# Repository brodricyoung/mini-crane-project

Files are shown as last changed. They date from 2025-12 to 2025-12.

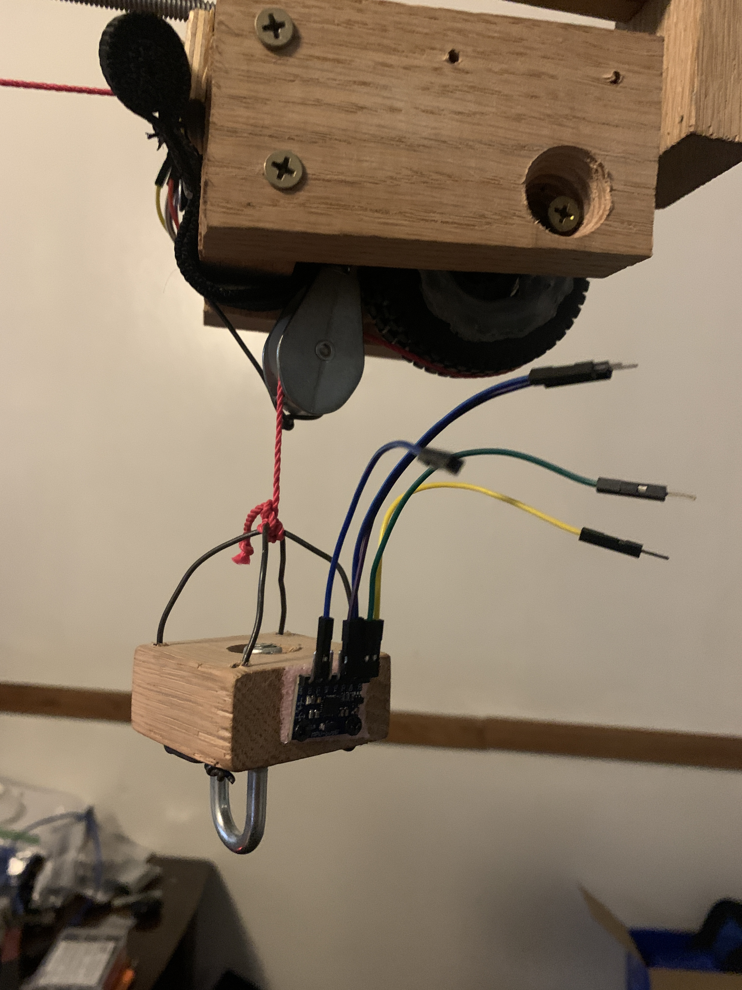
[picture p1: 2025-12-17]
Documentation/images/components-in-system/MPU-and-hook.JPG

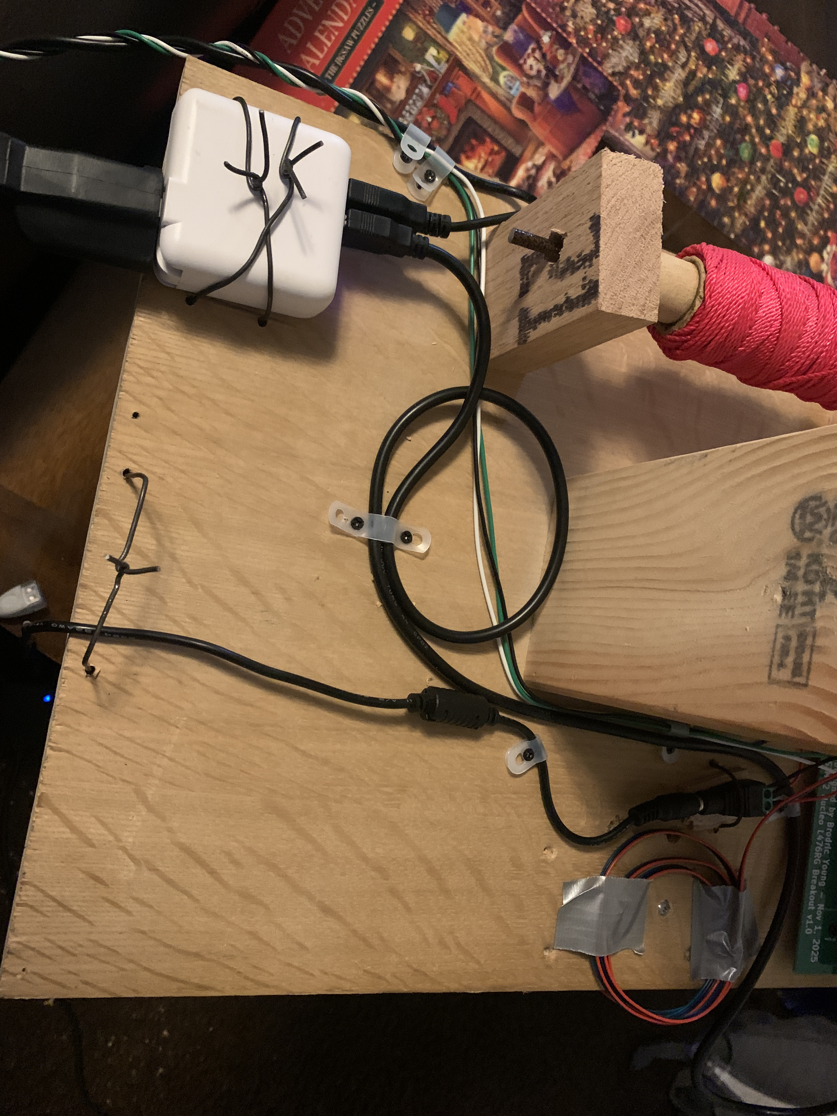
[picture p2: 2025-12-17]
Documentation/images/components-in-system/power-supply.JPG

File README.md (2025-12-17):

# Mini Crane Project

This repository contains the documentation and resources for my Mini Crane project, completed as part of my Individual Technical Project for professional career preparation. The project demonstrates a crane system controlled by an STM32 Nucleo microcontroller, with sensors and manual controls for crane motion and hook manipulation.

---

## 📄 Project Report

The full project report PDF is available here:

*(download for best experience navigating and for links)*

[Mini Crane Project Report](https://github.com/brodricyoung/mini-crane-project/blob/main/Documentation/Mini_Crane_Project_Report.pdf)

---

## 🖼 Images

Images of the crane assembly, components, and system setup, and schematics are included in the `images` folder:

[Images](./Documentation/images/)

---

## 🎥 Project Demo Video

Watch the project in action so far on YouTube:

[Mini Crane Demo #1](https://youtu.be/VVNfatb6yKk)

---

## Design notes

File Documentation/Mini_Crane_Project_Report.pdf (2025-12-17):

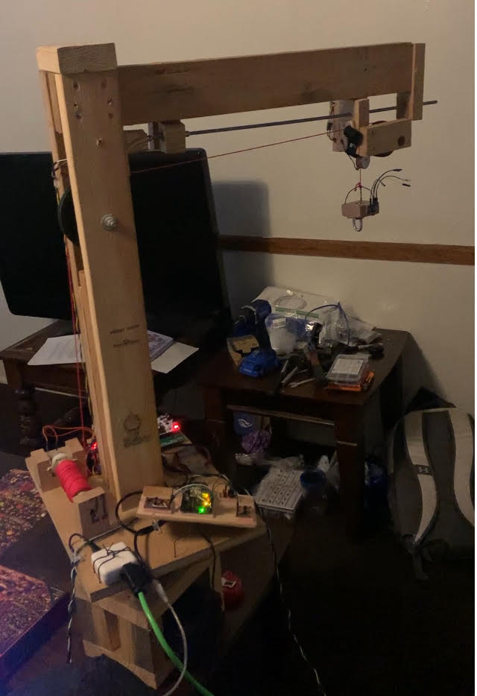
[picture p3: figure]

## Mini Crane Project

### Brodric Young

December 16, 2025

## Contents

1 Project Overview | 3
2 Specifications | 4
3 Project Procedures | 6
4 Code | 10
5 Conclusion | 11

1

## List of Tables

## List of Figures

1 | Pinout diagram for the STM32 microcontroller | | 6
2 | Pinout diagram for the Arduino microcontroller | | 7
3 | Pinout diagram for the L298N module driving the DC motors | | 7
4 | Pinout diagram for the L298N module driving the stepper motor | | 7
5 | Block diagram of the full system | | 8

2

## 1 Project Overview

The goal of this project was to design and build a miniature crane system controlled by an STM32 microcontroller, with the long-term goal of implementing automatic swing compensation for a suspended load. The crane was intended to demonstrate the integration of embedded systems, motor control, sensing, mechanical design, and communication between microcontrollers.

### 1.1 Github link

The full projects files can be found on Github here:

- Mini Crane Project (https://github.com/brodricyoung/mini-crane-project/tree/main)

### 1.2 System Overview

The mini crane consists of a wooden mechanical structure, multiple motors, sensors, and two microcontrollers communicating via UART. The system allows manual control through a handheld controller while collecting sensor data for future automation.

### 1.3 Objectives

- Designing a custom PCB to interface with an STM32 Nucleo board
- Controlling multiple motors (stepper and DC) for crane motion
- Measuring hook position using a rotary encoder
- Detecting load swing using an inertial measurement unit (IMU)
- Using sensors and motors for autonomous swing compensation

3

## 2 Specifications

The following parts list outlines the primary electrical, mechanical, and structural components used in the construction of the mini crane system. Components were selected to support motor control, sensor integration, and communication between microcontrollers while remaining modular and serviceable. Emphasis was placed on using commonly available hardware and development boards to allow for rapid prototyping, debugging, and future system expansion.

### 2.1 Parts List

- STM32 Nucleo development board (main crane controller) (https://www.st.com/en/evaluation-tools/nucleo-l476rg.html)
- Custom-designed STM32 breakout PCB (KiCad) (https://github.com/brodricyoung/mini-crane-project/tree/main/KiCad_files_for_PCB)
- Arduino microcontroller (handheld controller) (https://docs.arduino.cc/hardware/uno-rev3/)
- Two L298N motor driver modules (https://www.amazon.com/dp/B0CLYBPGP9?ref=ppx_yo2ov_dt_b_fed_asin_title)
- NEMA 17 stepper motor (crane rotation) (https://www.amazon.com/dp/B07SC8HJMC?ref=ppx_yo2ov_dt_b_fed_asin_title&th=1)
- Two 10 RPM DC gear motors (winch and trolley drive) (https://www.amazon.com/dp/B07S2KWRWQ?ref=ppx_yo2ov_dt_b_fed_asin_title&th=1)
- 1/4 in threaded rod and matching flange nut (trolley linear motion) (https://github.com/brodricyoung/mini-crane-project/blob/main/Documentation/images/components-in-system/trolley-and-threaded-rod.JPG)
- Rotary encoder module (rope length measurement) (https://www.amazon.com/dp/B0DFYLNWPJ?ref=ppx_yo2ov_dt_b_fed_asin_title&th=1)
- MPU-6050 IMU module (swing detection sensor) (https://www.amazon.com/dp/B01DK83ZYQ?ref=ppx_yo2ov_dt_b_fed_asin_title&th=1)
- Handheld controller protoboards with push buttons (motor control), buzzer, and LED (swing compensation indicators) (https://github.com/brodricyoung/mini-crane-project/blob/main/Documentation/images/components-in-system/handheld-arduino-controller.JPG)
- UART communication wiring between Arduino and STM32
- 5mm flange coupling connectors (motors) (https://www.amazon.com/dp/B08334MFVT?ref=ppx_yo2ov_dt_b_fed_asin_title&th=1)
- 6.35mm flange coupling connectors (threaded rod and rotary encoder) (https://www.amazon.com/dp/B08334YZ9V?ref=ppx_yo2ov_dt_b_fed_asin_title&th=1)
- Bearing for crane rotation (https://www.amazon.com/dp/B0BBL46B8Y?ref=ppx_yo2ov_dt_b_fed_asin_title&th=1)
- Pulleys and rope for winch mechanism
- Wooden structural components (frame and boom)
- 12V power supply (motor driver modules) (https://www.amazon.com/dp/B0C22Z8DPL?ref=ppx_yo2ov_dt_b_fed_asin_title)
- 5V USB power supply for microcontrollers (https://github.com/brodricyoung/mini-crane-project/blob/main/Documentation/images/components-in-system/power-supply.JPG)

4

### 2.2 System Images and Demonstration Media

This subsection provides external references to visual documentation of the completed mini crane system. High-resolution images showing each major component integrated into the final assembly, as well as a demonstration video of the system in operation, are hosted online in the project Github repository to avoid overloading the report with large media files. These resources offer additional context for the mechanical layout, wiring, and overall system behavior.

- GitHub repository folder containing system images (https://github.com/brodricyoung/mini-crane-project/tree/main/Documentation/images/components-in-system)
- Project demonstration video (https://www.youtube.com/watch?v=VVNfatb6yKk)

5

## 3 Project Procedures

This section documents the design and implementation of the mini crane system using a combination of pinout diagrams, block diagrams, and written descriptions. Electrical schematics were created in the form of detailed pinout diagrams using Google Sheets to clearly illustrate the connections between the STM32 Nucleo board, motor drivers, sensors, and peripheral devices. This approach allowed for rapid iteration and easy modification as the project evolved.
In addition, a system-level block diagram is provided to describe the overall architecture of the crane, including control flow, power distribution, and communication between subsystems. The written block diagram description complements the visual diagram by explaining the functional role of each subsystem and how they interact during operation. Together, these materials provide a clear representation of both the electrical and logical structure of the project.

Notes:

- The ”slew” in the diagrams refers to the NEMA 17 stepper motor
- The ”winch” and ”trolley” in the diagrams refer to the two 10 RPM DC gear motors
- ”L298N [A]” in the diagrams refers to the L298N motor driver module driving the two DC motors
- ”L298N [B]” in the diagrams refers to the L298N motor driver module driving the NEMA 17 stepper motor

### 3.1 Pinout Diagrams

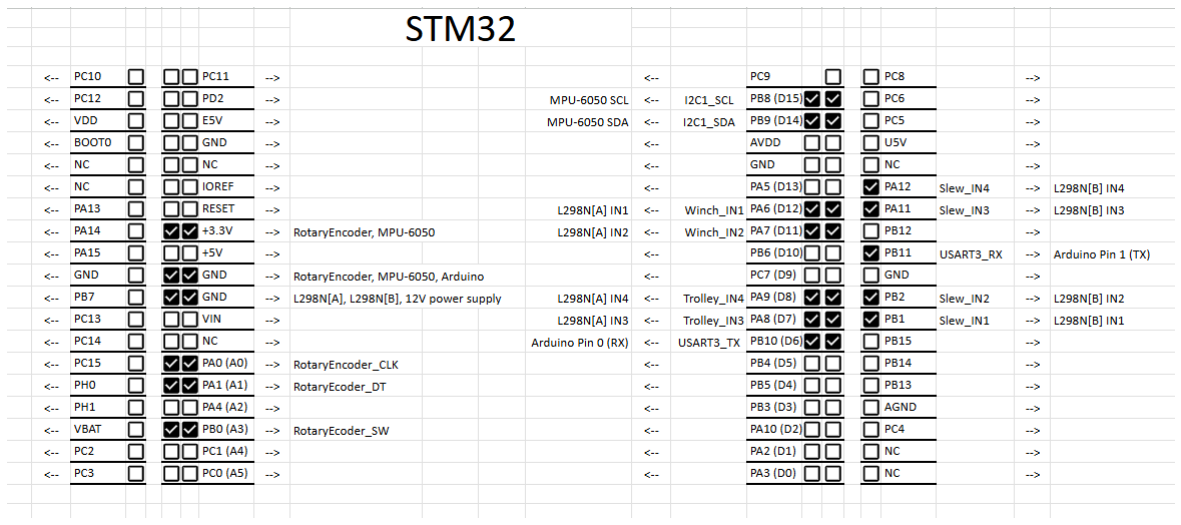
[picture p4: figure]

Figure 1: Pinout diagram for the STM32 microcontroller

6

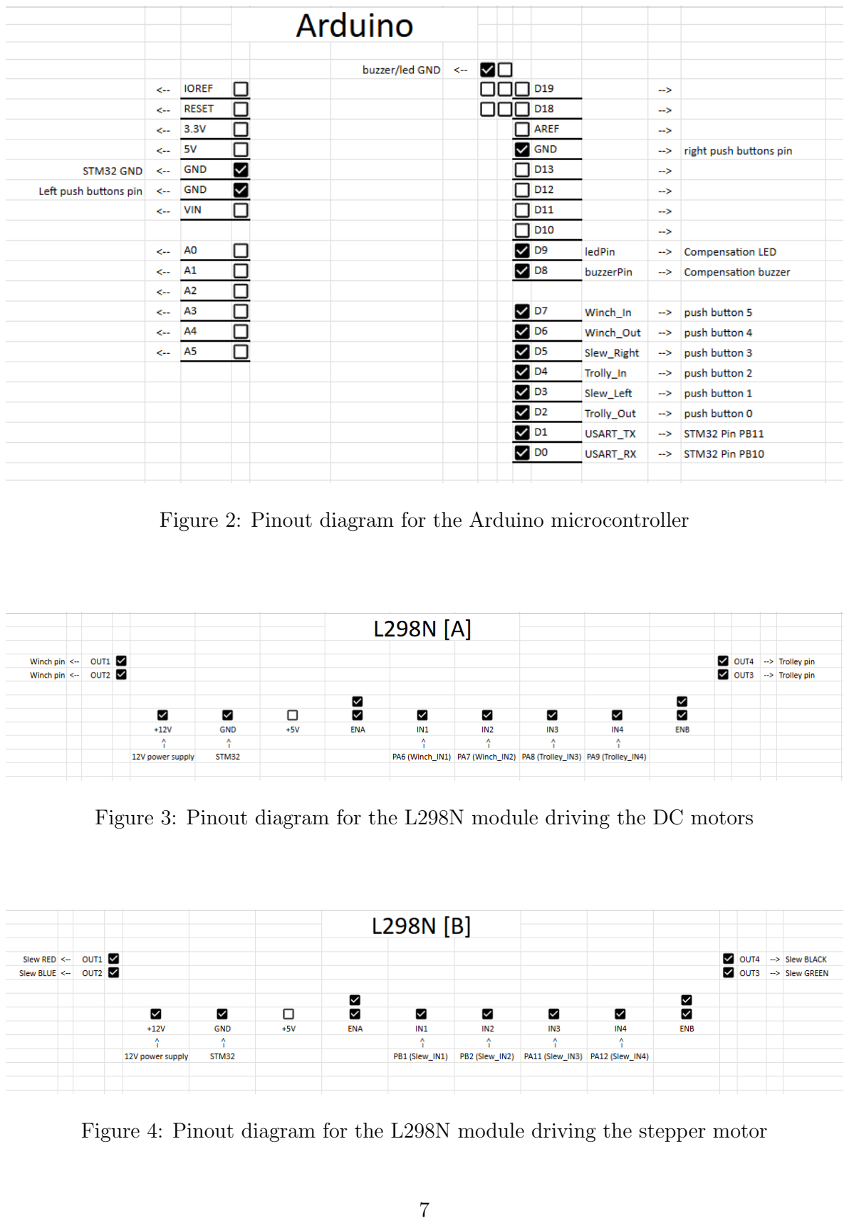
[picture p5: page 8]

Figure 2: Pinout diagram for the Arduino microcontroller

Figure 3: Pinout diagram for the L298N module driving the DC motors

Figure 4: Pinout diagram for the L298N module driving the stepper motor

7

### 3.2 Block Diagram

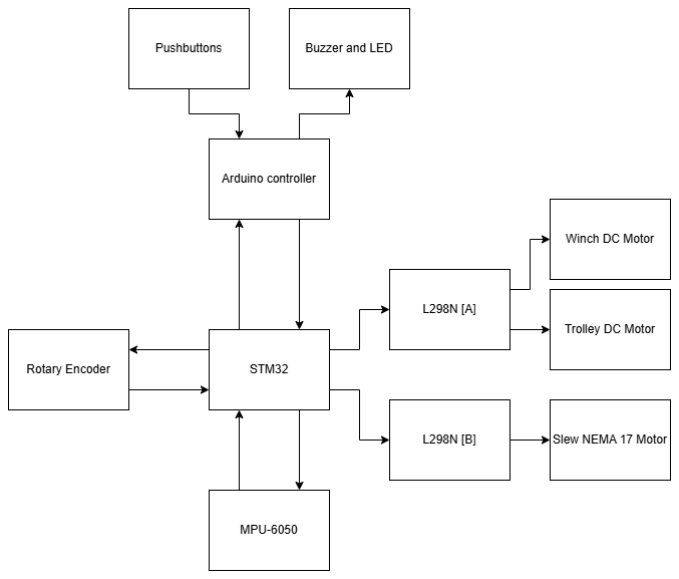
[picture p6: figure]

Figure 5: Block diagram of the full system

### 3.3 Block Diagram Description

- Handheld Controller

– Arduino microcontroller

– D-pad and additional push buttons

– Communicates with STM32 via UART

- STM32 Nucleo Board

– Receives commands from handheld controller

8

– Controls motor driver modules

– Reads sensor data

– Outputs diagnostic data via serial terminal (PuTTY)

- Motor Subsystem

– Stepper motor for crane rotation (tread system)

– DC motor for winch operation (hook up/down)

– DC motor driving threaded rod for trolley movement

- Sensor Subsystem

– Rotary encoder for rope length measurement

– MPU-6050 IMU for load swing detection (partially implemented)

- Indicators

– LED indicator for swing compensation status

– Buzzer for swing compensation notification

9

## 4 Code

All source code developed for this project is maintained in a public GitHub repository. Due to the size and modular structure of the codebase, full source listings are not included directly in this report. Instead, this section provides links to the repository and individual source files for reference. This approach allows for easier navigation, version control, and future expansion while keeping the report concise and readable.

### 4.1 Source Code Repository

The complete source code for the STM32 and the Arduino are available at the following GitHub repositories:

- STM32 code folder (https://github.com/brodricyoung/mini-crane-project/tree/main/stm32/mini_crane_STM32/Core/Src)
- Arduino code (there is only one file for the arduino) (https://github.com/brodricyoung/mini-crane-project/tree/main/arduino/mini_crane_controller)

### 4.2 STM32 Individual Code Files

- main.c (https://github.com/brodricyoung/mini-crane-project/blob/main/stm32/mini_crane_STM32/Core/Src/main.c)
- main.h (https://github.com/brodricyoung/mini-crane-project/blob/main/stm32/mini_crane_STM32/Core/Inc/main.h)
- motors.c (https://github.com/brodricyoung/mini-crane-project/blob/main/stm32/mini_crane_STM32/Core/Src/motors.c)
- motors.h (https://github.com/brodricyoung/mini-crane-project/blob/main/stm32/mini_crane_STM32/Core/Inc/motors.h)
- rotary encoder.c (https://github.com/brodricyoung/mini-crane-project/blob/main/stm32/mini_crane_STM32/Core/Src/rotary_encoder.c)
- rotary encoder.h (https://github.com/brodricyoung/mini-crane-project/blob/main/stm32/mini_crane_STM32/Core/Inc/rotary_encoder.h)
- arduino comm.c (https://github.com/brodricyoung/mini-crane-project/blob/main/stm32/mini_crane_STM32/Core/Src/arduino_comm.c)
- arduino comm.h (https://github.com/brodricyoung/mini-crane-project/blob/main/stm32/mini_crane_STM32/Core/Inc/arduino_comm.h)
- swing sensor.c (https://github.com/brodricyoung/mini-crane-project/blob/main/stm32/mini_crane_STM32/Core/Src/swing_sensor.c)
- swing sensor.h (https://github.com/brodricyoung/mini-crane-project/blob/main/stm32/mini_crane_STM32/Core/Inc/swing_sensor.h)

10

## 5 Conclusion

### 5.1 Performance Summary

The mini crane system was successfully constructed and demonstrated manual control of multiple crane motions, including hook lifting, trolley movement, and limited base rotation. The rotary encoder functioned correctly and provided real-time feedback of rope length via serial output. Communication between the handheld Arduino controller and the STM32 Nucleo board over UART operated as intended.

### 5.2 Project Evaluation

The project partially met expectations. While the mechanical structure and electronic control systems operated, several limitations were identified:

- The crane rotation mechanism suffered from alignment and traction issues.
- The stepper motor lacked sufficient torque in some situations.
- The trolley movement was functional but extremely slow due to low motor speed.
- The swing compensation system was not fully implemented due to difficulty reading data from the MPU-6050 sensor.

Despite these challenges, the core system architecture was validated.

### 5.3 Key Learning Outcomes

This project provided significant learning experiences, including:

- Designing and fabricating a custom PCB independently.
- Working with rotary encoders for position measurement.
- Integrating an IMU for motion sensing.
- Implementing UART communication between microcontrollers.
- Debugging complex electromechanical systems.
- Gaining hands-on experience with mechanical design, alignment, and torque considerations.

Additionally, the project reinforced the importance of careful motor selection and mechanical tolerances.

11

### 5.4 Future Improvements

With additional time and resources, the following enhancements would be implemented:

- Successfully implement and calibrate the MPU-6050 swing detection system.
- Complete the autonomous swing compensation algorithm.
- Upgrade motors to higher torque and higher speed models.
- Redesign the crane rotation mechanism for improved alignment and traction.
- Increase mechanical rigidity and optimize pulley systems.
- Refine PCB layout and cable management.

These improvements would move the project closer to a fully autonomous, reliable, and functional mini crane system.

12

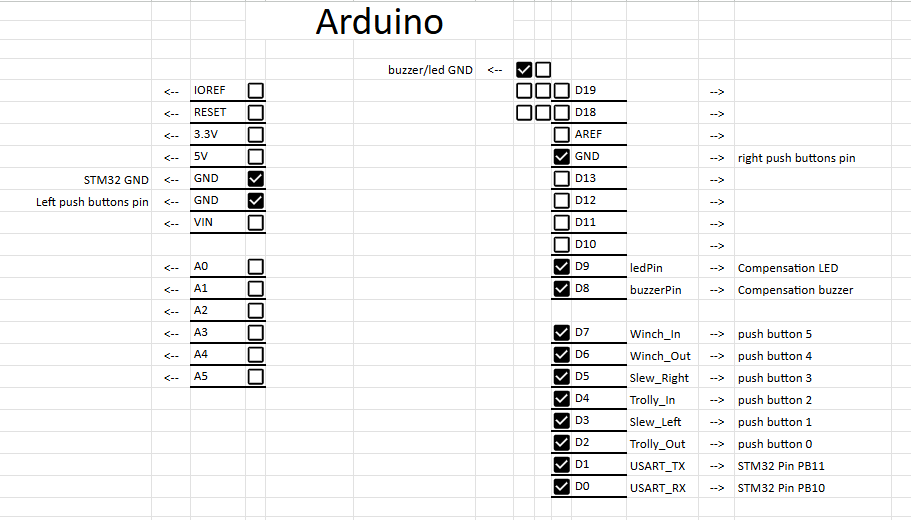
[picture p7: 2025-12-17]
Documentation/images/schematics/pinout-arduino.png

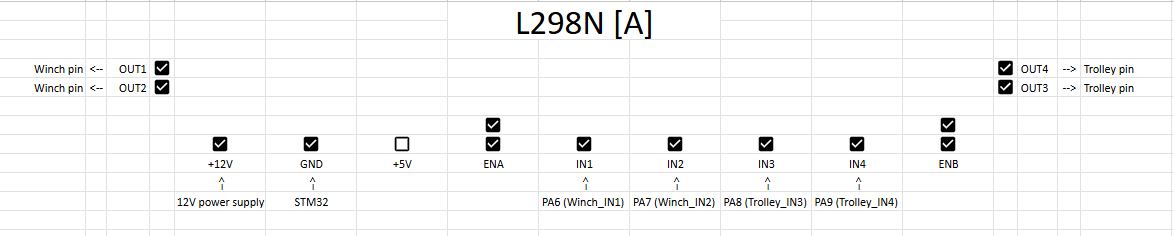
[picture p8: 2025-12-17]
Documentation/images/schematics/pinout-L298N-A.png

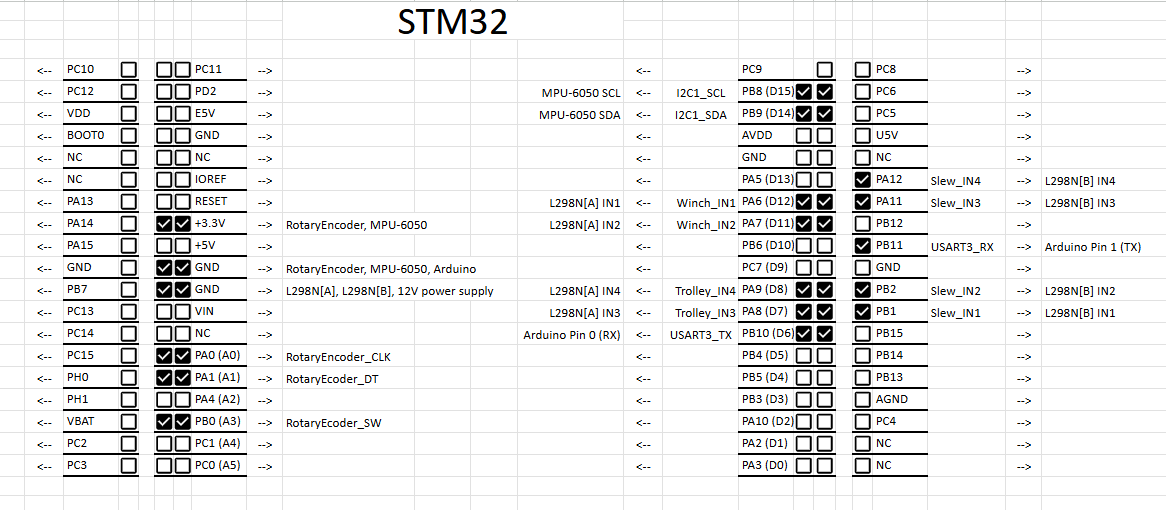
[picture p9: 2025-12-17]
Documentation/images/schematics/pinout-stm32.png

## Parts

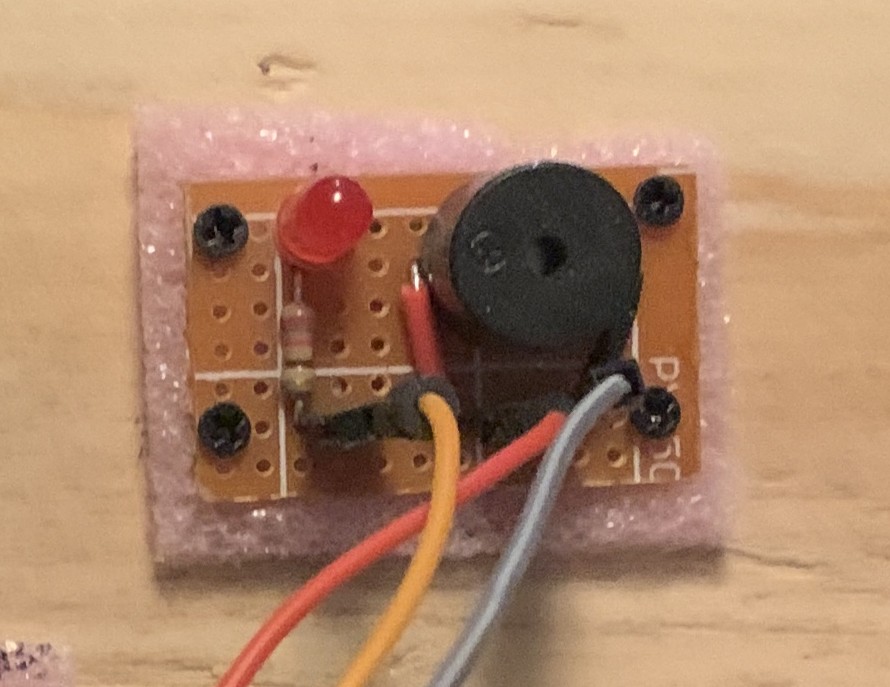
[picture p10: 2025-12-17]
Documentation/images/components-in-system/buzzer-and-led-on-controller.JPG

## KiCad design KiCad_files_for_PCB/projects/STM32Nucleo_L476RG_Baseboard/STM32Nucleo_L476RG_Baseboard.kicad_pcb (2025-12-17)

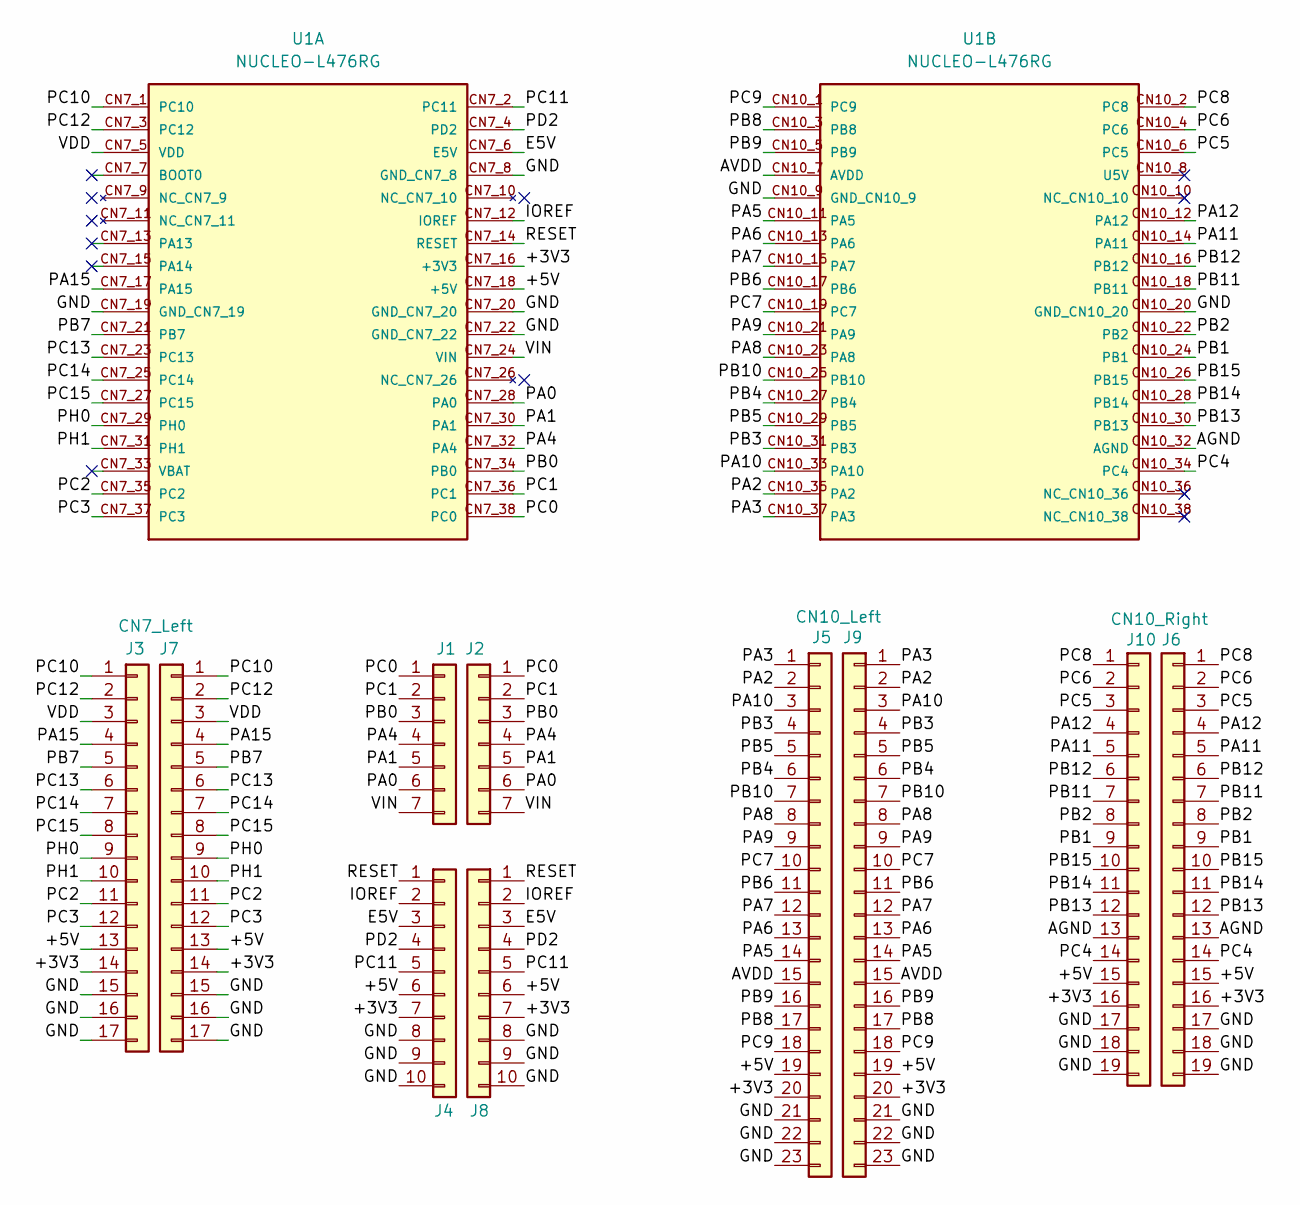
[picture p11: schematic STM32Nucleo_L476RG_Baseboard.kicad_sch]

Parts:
J1: Conn_01x07; PinSocket_1x07_P2.54mm_Vertical
J2: Conn_01x07; PinHeader_1x07_P2.54mm_Vertical
J3: CN7_Left; PinHeader_1x17_P2.54mm_Vertical
J4: Conn_01x10; PinSocket_1x10_P2.54mm_Vertical
J5: CN10_Left; PinHeader_1x23_P2.54mm_Vertical
J6: CN10_Right; PinHeader_1x19_P2.54mm_Vertical
J7: CN7_Left; PinSocket_1x17_P2.54mm_Vertical
J8: Conn_01x10; PinHeader_1x10_P2.54mm_Vertical
J9: CN10_Left; PinSocket_1x23_P2.54mm_Vertical
J10: CN10_Right; PinSocket_1x19_P2.54mm_Vertical
U1: NUCLEO-L476RG; MODULE_NUCLEO-L476RG; PARTREV 15

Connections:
/+3V3: J3.14, J4.7, J5.20, J6.16, J7.14, J8.7, J9.20, J10.16, U1.CN7_16 (+3V3)
/+5V: J3.13, J4.6, J5.19, J6.15, J7.13, J8.6, J9.19, J10.15, U1.CN7_18 (+5V)
/AGND: J6.13, J10.13, U1.CN10_32 (AGND)
/AVDD: J5.15, J9.15, U1.CN10_7 (AVDD)
/E5V: J4.3, J8.3, U1.CN7_6 (E5V)
/GND: J3.15, J3.16, J3.17, J4.8, J4.9, J4.10, J5.21, J5.22, J5.23, J6.17, J6.18, J6.19, J7.15, J7.16, J7.17, J8.8, J8.9, J8.10, J9.21, J9.22, J9.23, J10.17, J10.18, J10.19, U1.CN7_8 (GND_CN7_8), U1.CN7_19 (GND_CN7_19), U1.CN7_20 (GND_CN7_20), U1.CN7_22 (GND_CN7_22), U1.CN10_9 (GND_CN10_9), U1.CN10_20 (GND_CN10_20)
/IOREF: J4.2, J8.2, U1.CN7_12 (IOREF)
/PA0: J1.6, J2.6, U1.CN7_28 (PA0)
/PA1: J1.5, J2.5, U1.CN7_30 (PA1)
/PA2: J5.2, J9.2, U1.CN10_35 (PA2)
/PA3: J5.1, J9.1, U1.CN10_37 (PA3)
/PA4: J1.4, J2.4, U1.CN7_32 (PA4)
/PA5: J5.14, J9.14, U1.CN10_11 (PA5)
/PA6: J5.13, J9.13, U1.CN10_13 (PA6)
/PA7: J5.12, J9.12, U1.CN10_15 (PA7)
/PA8: J5.8, J9.8, U1.CN10_23 (PA8)
/PA9: J5.9, J9.9, U1.CN10_21 (PA9)
/PA10: J5.3, J9.3, U1.CN10_33 (PA10)
/PA11: J6.5, J10.5, U1.CN10_14 (PA11)
/PA12: J6.4, J10.4, U1.CN10_12 (PA12)
/PA15: J3.4, J7.4, U1.CN7_17 (PA15)
/PB0: J1.3, J2.3, U1.CN7_34 (PB0)
/PB1: J6.9, J10.9, U1.CN10_24 (PB1)
/PB2: J6.8, J10.8, U1.CN10_22 (PB2)
/PB3: J5.4, J9.4, U1.CN10_31 (PB3)
/PB4: J5.6, J9.6, U1.CN10_27 (PB4)
/PB5: J5.5, J9.5, U1.CN10_29 (PB5)
/PB6: J5.11, J9.11, U1.CN10_17 (PB6)
/PB7: J3.5, J7.5, U1.CN7_21 (PB7)
/PB8: J5.17, J9.17, U1.CN10_3 (PB8)
/PB9: J5.16, J9.16, U1.CN10_5 (PB9)
/PB10: J5.7, J9.7, U1.CN10_25 (PB10)
/PB11: J6.7, J10.7, U1.CN10_18 (PB11)
/PB12: J6.6, J10.6, U1.CN10_16 (PB12)
/PB13: J6.12, J10.12, U1.CN10_30 (PB13)
/PB14: J6.11, J10.11, U1.CN10_28 (PB14)
/PB15: J6.10, J10.10, U1.CN10_26 (PB15)
/PC0: J1.1, J2.1, U1.CN7_38 (PC0)
/PC1: J1.2, J2.2, U1.CN7_36 (PC1)
/PC2: J3.11, J7.11, U1.CN7_35 (PC2)
/PC3: J3.12, J7.12, U1.CN7_37 (PC3)
/PC4: J6.14, J10.14, U1.CN10_34 (PC4)
/PC5: J6.3, J10.3, U1.CN10_6 (PC5)
/PC6: J6.2, J10.2, U1.CN10_4 (PC6)
/PC7: J5.10, J9.10, U1.CN10_19 (PC7)
/PC8: J6.1, J10.1, U1.CN10_2 (PC8)
/PC9: J5.18, J9.18, U1.CN10_1 (PC9)
/PC10: J3.1, J7.1, U1.CN7_1 (PC10)
/PC11: J4.5, J8.5, U1.CN7_2 (PC11)
/PC12: J3.2, J7.2, U1.CN7_3 (PC12)
/PC13: J3.6, J7.6, U1.CN7_23 (PC13)
/PC14: J3.7, J7.7, U1.CN7_25 (PC14)
/PC15: J3.8, J7.8, U1.CN7_27 (PC15)
/PD2: J4.4, J8.4, U1.CN7_4 (PD2)
/PH0: J3.9, J7.9, U1.CN7_29 (PH0)
/PH1: J3.10, J7.10, U1.CN7_31 (PH1)
/RESET: J4.1, J8.1, U1.CN7_14 (RESET)
/VDD: J3.3, J7.3, U1.CN7_5 (VDD)
/VIN: J1.7, J2.7, U1.CN7_24 (VIN)

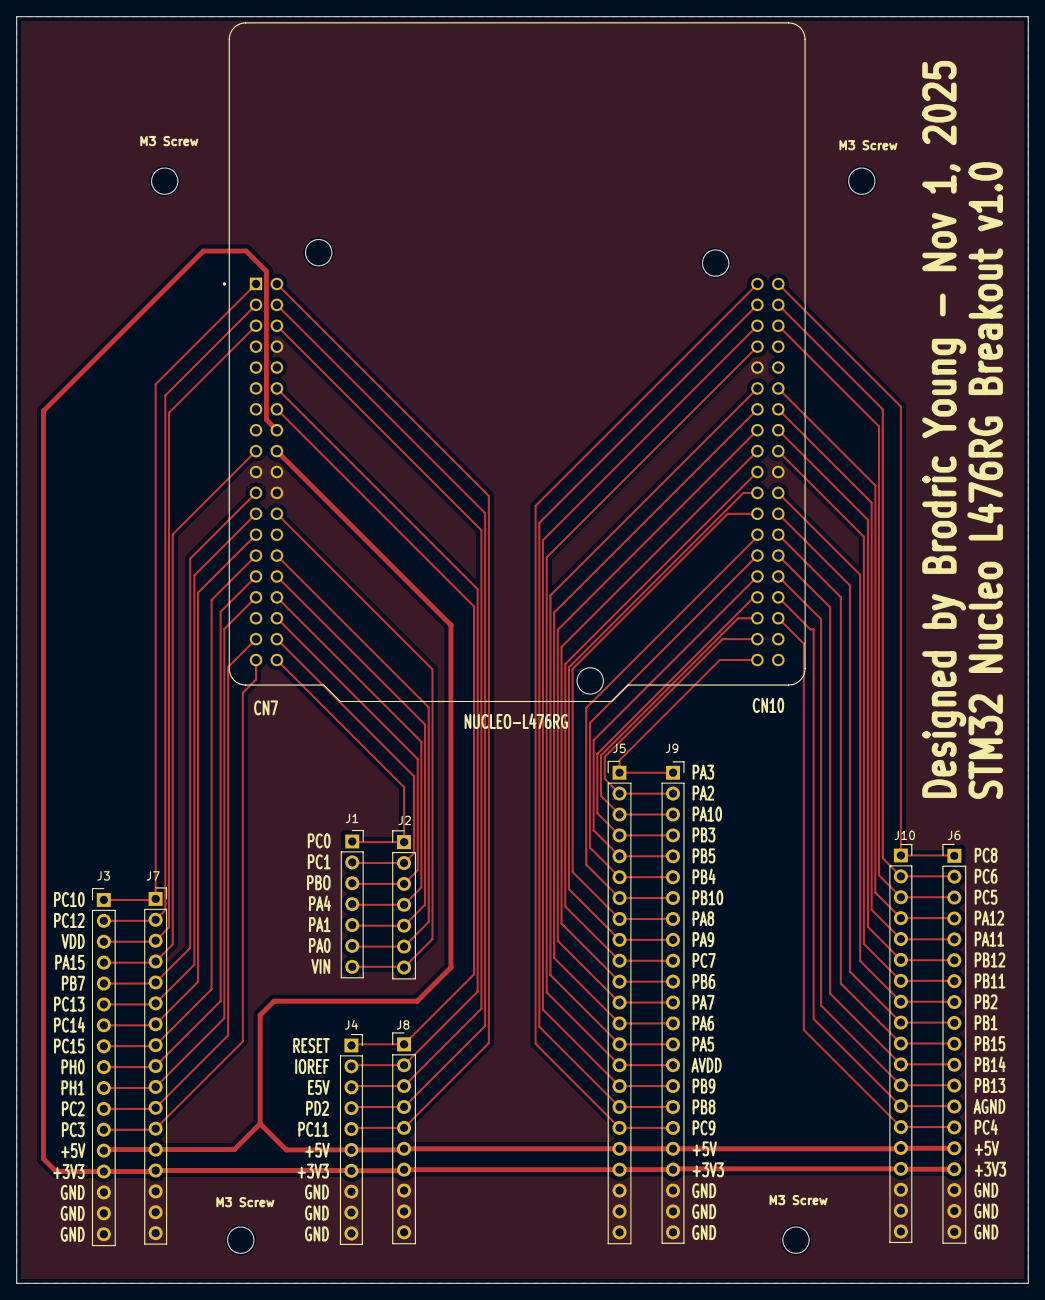
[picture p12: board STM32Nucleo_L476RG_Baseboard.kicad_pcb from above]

Board: 2 copper layers, 123.0 x 154.0 mm, 11 parts (0 on the bottom side), 59 nets.

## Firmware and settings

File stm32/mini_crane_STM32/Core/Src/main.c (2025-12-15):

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
/* Includes ------------------------------------------------------------------*/
#include "main.h"

/* USER CODE BEGIN Includes */
#include <stdio.h>
#include <stdbool.h>
#include <math.h>
#include "arduino_comm.h"
#include "motors.h"
#include "rotary_encoder.h"
#include "swing_sensor.h"



/* USER CODE END Includes */

I2C_HandleTypeDef hi2c1;

TIM_HandleTypeDef htim2;
TIM_HandleTypeDef htim5;

UART_HandleTypeDef huart2;
UART_HandleTypeDef huart3;

/* USER CODE BEGIN PV */
bool compensation_in_progress = false;
bool prev_compensation_state = false;

RotaryEncoder_t ropeEncoder;

extern I2C_HandleTypeDef hi2c1;
SwingSensor_t swingData;

uint8_t btn;
ButtonEvent evt;
/* USER CODE END PV */

void SystemClock_Config(void);
static void MX_GPIO_Init(void);
static void MX_USART2_UART_Init(void);
static void MX_TIM5_Init(void);
static void MX_USART3_UART_Init(void);
static void MX_TIM2_Init(void);
static void MX_I2C1_Init(void);
/* USER CODE BEGIN PFP */
void TIM2_IRQHandler(void);
void Arduino_To_Motor_Control(void);
/* USER CODE END PFP */

/**
  * @brief  The application entry point.
  * @retval int
  */
int main(void)
{

  /* MCU Configuration--------------------------------------------------------*/

  /* Reset of all peripherals, Initializes the Flash interface and the Systick. */
  HAL_Init();

  /* Configure the system clock */
  SystemClock_Config();

  /* Initialize all configured peripherals */
  MX_GPIO_Init();
  MX_USART2_UART_Init();
  MX_TIM5_Init();
  MX_USART3_UART_Init();
  MX_TIM2_Init();
  MX_I2C1_Init();
  /* USER CODE BEGIN 2 */
  SwingSensor_Init(&hi2c1);
  HAL_Delay(1000);  // let IMU stabilize
  SwingSensor_CalibrateZero();


  RE_Init(&ropeEncoder, &htim2, 60.0f, 2.5f);   // 60 ticks (30 detents) per revelution, 2-1/2" diameter

  ArduinoComm_Init(&huart3);

  DCMotor_Init();
  SlewMotor_Init();


  int32_t count;
  float dist;
  int32_t lastCount = 0;
  float   lastDist  = 0.0f;


  uint32_t last = 0;

  printf("\033[2J\033[H");
  /* USER CODE END 2 */

  /* Infinite loop */
  /* USER CODE BEGIN WHILE */
  while (1)
  {
    /* USER CODE END WHILE */

    /* USER CODE BEGIN 3 */

// ----------- Compensation buzzer and LED ---------------------------
	  // using B1 just as a test/simulation going from STM32 to arduino
	  if (HAL_GPIO_ReadPin(B1_GPIO_Port, B1_Pin) == GPIO_PIN_RESET) {
		  compensation_in_progress = true;
	  }
	  else {
		  compensation_in_progress = false;
	  }
	  // turn on buzzer and LED on controller if compensation_in_progress is true
	  CheckCompensationAndNotify();
//	  test_buzzer_uart();



// ------------- Rotary Encoder -------------
// ----- This is done in the motor control function, but this one will display it anytime it changes, not just if a motor is going

//	  RE_Update(&ropeEncoder);
//	  count = RE_GetCount(&ropeEncoder);
//	  dist = RE_GetDistanceInches(&ropeEncoder);
//
//	  if (count != lastCount || dist != lastDist) {
//		  printf("Count=%ld  Distance=%.3f in\r\n", count, dist);
//	      lastCount = count;
//	      lastDist = dist;
//	  }




// ------------- MPU 6050 swing sensor -----------------------
//	  if (HAL_GetTick() - last >= 20) {  // 20 ms = 50 Hz
//		  SwingSensor_Update();
//
//		  float angle = SwingSensor_GetAngle();
//		  bool swinging = SwingSensor_IsSwinging();
//
//		  printf("Angle: %.3f    |%d\r\n", angle, swinging);
//		// Use these variables in your swing compensation logic here:
//		// angle  → filtered swing angle
//		// swinging → true/false
//
//	   	  last = HAL_GetTick();
//	  }
//
//	  HAL_Delay(100);


// ----------------- Arduino button press to motor driving -------------------
	  Arduino_To_Motor_Control();

  }
  /* USER CODE END 3 */
}

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
/* USER CODE BEGIN 4 */
// Redirect printf() to USB UART (huart2)
int __io_putchar(int ch) {
    HAL_UART_Transmit(&huart2, (uint8_t *)&ch, 1, HAL_MAX_DELAY);
    return ch;
}


void HAL_TIM_PeriodElapsedCallback(TIM_HandleTypeDef *htim)
{
    if (htim->Instance == TIM5) {Stepper_Timer_Callback();}
}


void HAL_UART_RxCpltCallback(UART_HandleTypeDef *huart) {
    ArduinoComm_UART_RxCallback(huart);
}

void HAL_GPIO_EXTI_Callback(uint16_t GPIO_Pin)
{
    if (GPIO_Pin == RotaryEncoder_SW_Pin) {
        RE_ButtonPressed(&ropeEncoder); // reset rotary encoder length to 0
    }
}

void Arduino_To_Motor_Control(void)
{
	int32_t count;
	float dist;

    uint8_t btn;
    ButtonEvent evt;

    if (ArduinoComm_GetButtonEvent(&btn, &evt))
    {
        if (evt == BUTTON_PRESS)
        {
            switch (btn)
            {
                case 0:
                    TrolleyMotor_Set(FORWARD);
                    printf("Trolley forward\r\n");
                    break;

                case 1:
                    SlewMotor_Set(140.0f, COUNTERCLOCKWISE);
                    printf("Slew CounterClockwise\r\n");
                    break;

                case 2:
                    TrolleyMotor_Set(REVERSE);
                    printf("Trolley backward\r\n");
                    break;

                case 3:
                    SlewMotor_Set(140.0f, CLOCKWISE);
                    printf("Slew Clockwise\r\n");
                    break;

                case 4:
                	// winch motor pins from L298N Motor driver module arent working, combined it with trolley for demo
//                    WinchMotor_Set(FORWARD);
                	TrolleyMotor_Set(FORWARD);
                    printf("Winch out | ");

                    // display rotary encoder information
					RE_Update(&ropeEncoder);
					count = RE_GetCount(&ropeEncoder);
					dist = RE_GetDistanceInches(&ropeEncoder);
					printf("Count=%ld  Distance=%.3f in\r\n", count, dist);
                    break;

                case 5:
                	// winch motor pins from L298N Motor driver module arent working, combined it with trolley for demo
//                    WinchMotor_Set(REVERSE);
                	TrolleyMotor_Set(REVERSE);
                    printf("Winch in  | ");

                    // display rotary encoder information
					RE_Update(&ropeEncoder);
					count = RE_GetCount(&ropeEncoder);
					dist = RE_GetDistanceInches(&ropeEncoder);
					printf("Count=%ld  Distance=%.3f in\r\n", count, dist);
                    break;

                default:
                    printf("Unknown button %d\r\n", btn);
                    break;
            }
        }
        else // BUTTON_RELEASE
        {
            switch (btn)
            {
                case 0:
                case 2:
                    TrolleyMotor_Set(STOP);
                    printf("Trolley stop\r\n");
                    break;

                case 1:
                case 3:
                    SlewMotor_Set(10.0f, HOLD);
                    SlewMotor_Coast();
                    printf("Slew coast\r\n");
                    break;

                case 4:
                case 5:
                	// winch motor pins from L298N Motor driver module arent working, combined it with trolley for demo
//                    WinchMotor_Set(STOP);
                	TrolleyMotor_Set(STOP);
                    printf("Winch stop\r\n");
                    break;

                default:
                    printf("Unknown button %d\r\n", btn);
                    break;
            }
        }
    }

    HAL_Delay(10);
}
/* USER CODE END 4 */
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


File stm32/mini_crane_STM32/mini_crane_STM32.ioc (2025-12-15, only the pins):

Mcu.UserName=STM32L476RGTx
PA0.GPIO_Label=RotaryEncoder_CLK
PA0.Signal=S_TIM2_CH1
PA1.GPIO_Label=RotaryEncoder_DT
PA1.Signal=S_TIM2_CH2
PA11.GPIO_Label=Slew_IN3
PA11.Signal=GPIO_Output
PA12.GPIO_Label=Slew_IN4
PA12.Signal=GPIO_Output
PA2.GPIO_Label=USART_TX
PA2.Signal=USART2_TX
PA3.GPIO_Label=USART_RX
PA3.Signal=USART2_RX
PA5.GPIO_Label=LD2 [green Led]
PA5.Signal=GPIO_Output
PA6.GPIO_Label=Winch_IN1
PA6.Signal=GPIO_Output
PA7.GPIO_Label=Winch_IN2
PA7.Signal=GPIO_Output
PA8.GPIO_Label=Trolley_IN3
PA8.Signal=GPIO_Output
PA9.GPIO_Label=Trolley_IN4
PA9.Signal=GPIO_Output
PB0.GPIO_Label=RotaryEncoder_SW
PB0.Signal=GPXTI0
PB1.GPIO_Label=Slew_IN1
PB1.Signal=GPIO_Output
PB10.Signal=USART3_TX
PB11.Signal=USART3_RX
PB2.GPIO_Label=Slew_IN2
PB2.Signal=GPIO_Output
PB8.Signal=I2C1_SCL
PB9.Signal=I2C1_SDA
PC13.GPIO_Label=B1 [Blue PushButton]
PC13.Signal=GPXTI13

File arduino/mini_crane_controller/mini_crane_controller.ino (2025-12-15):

// Number of buttons
const uint8_t NUM_BUTTONS = 6;

// Pins for the buttons
uint8_t buttonPins[NUM_BUTTONS] = {2, 3, 4, 5, 6, 7};

// Track the previous button states so we only send stop once
bool prevState[NUM_BUTTONS];

const int buzzerPin = 8;
const int ledPin = 9;

// Serial input buffer
String inputString = "";
bool stringComplete = false;

void setup() {
  Serial.begin(115200);

  // Configure button pins as INPUT_PULLUP
  for (int i = 0; i < NUM_BUTTONS; i++) {
    pinMode(buttonPins[i], INPUT_PULLUP);
    prevState[i] = HIGH; // HIGH = not pressed
  }

  pinMode(buzzerPin, OUTPUT);
  pinMode(ledPin, OUTPUT);
}

void loop() {

  // ----------------------------
  // 1. Handle incoming UART data
  // ----------------------------
  if (stringComplete) {
    processCommand(inputString);
    inputString = "";
    stringComplete = false;
  }

  // ----------------------------
  // 2. Handle button reading
  // ----------------------------
  for (int i = 0; i < NUM_BUTTONS; i++) {

    bool current = digitalRead(buttonPins[i]);

    // ACTIVE LOW → pressed = LOW
    if (current == LOW) {
      Serial.print("BTN");
      Serial.print(i);
      Serial.println("_PRESS");
    }

    // Detect release edge
    if (current == HIGH && prevState[i] == LOW) {
      Serial.print("BTN");
      Serial.print(i);
      Serial.println("_RELEASE");
    }

    prevState[i] = current;
  }

  delay(20); // Simple debounce + reduce spam
}


// ----------------------------------------------------
// UART receive interrupt-style buffer (non-blocking)
// ----------------------------------------------------
void serialEvent() {
  while (Serial.available()) {
    char inChar = (char)Serial.read();
    if (inChar == '\n') {
      stringComplete = true;
    } else {
      inputString += inChar;
    }
  }
}


// ----------------------------------------------------
// PROCESS COMMANDS FROM STM32
// ----------------------------------------------------
void processCommand(String cmd) {

  // Turn buzzer ON
  if (cmd == "BUZZ_ON") {
    tone(buzzerPin, 75);     // 75 Hz
    digitalWrite(ledPin, HIGH);
  }

  // Turn buzzer OFF
  else if (cmd == "BUZZ_OFF") {
    noTone(buzzerPin);
    digitalWrite(ledPin, LOW);
  }
}

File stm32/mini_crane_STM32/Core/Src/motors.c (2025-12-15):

#include "motors.h"

// ==== STATIC DATA ====

static const uint8_t step_seq[4][4] = {
    {1,0,1,0},
    {1,0,0,1},
    {0,1,0,1},
    {0,1,1,0}
};

static volatile int step_index = 0;
static volatile int step_dir = 0;                 // 1=CW, -1=CCW, 0=hold
static volatile uint32_t step_interval_ms = 10;   // ms per step
static const int steps_per_rev = 200;
static uint8_t coast_flag = 0;

// ==== PRIVATE PROTOTYPES ====
static void Stepper_SetPins(int idx);

// ==== DC MOTOR API IMPLEMENTATION ====

void DCMotor_Init(void)
{
    WinchMotor_Set(STOP);
    TrolleyMotor_Set(STOP);
}

void WinchMotor_Set(DCMotorDirection direction)
{
    switch (direction)
    {
        case FORWARD:
            HAL_GPIO_WritePin(Winch_IN2_GPIO_Port, Winch_IN2_Pin, GPIO_PIN_RESET);
            HAL_GPIO_WritePin(Winch_IN1_GPIO_Port, Winch_IN1_Pin, GPIO_PIN_SET);
            break;

        case REVERSE:
            HAL_GPIO_WritePin(Winch_IN1_GPIO_Port, Winch_IN1_Pin, GPIO_PIN_RESET);
            HAL_GPIO_WritePin(Winch_IN2_GPIO_Port, Winch_IN2_Pin, GPIO_PIN_SET);
            break;

        case STOP:
        default:
            HAL_GPIO_WritePin(Winch_IN1_GPIO_Port, Winch_IN1_Pin, GPIO_PIN_RESET);
            HAL_GPIO_WritePin(Winch_IN2_GPIO_Port, Winch_IN2_Pin, GPIO_PIN_RESET);
            break;
    }
}

void TrolleyMotor_Set(DCMotorDirection direction)
{
    switch (direction)
    {
        case FORWARD:
            HAL_GPIO_WritePin(Trolley_IN4_GPIO_Port, Trolley_IN4_Pin, GPIO_PIN_RESET);
            HAL_GPIO_WritePin(Trolley_IN3_GPIO_Port, Trolley_IN3_Pin, GPIO_PIN_SET);
            break;

        case REVERSE:
            HAL_GPIO_WritePin(Trolley_IN3_GPIO_Port, Trolley_IN3_Pin, GPIO_PIN_RESET);
            HAL_GPIO_WritePin(Trolley_IN4_GPIO_Port, Trolley_IN4_Pin, GPIO_PIN_SET);
            break;

        case STOP:
        default:
            HAL_GPIO_WritePin(Trolley_IN3_GPIO_Port, Trolley_IN3_Pin, GPIO_PIN_RESET);
            HAL_GPIO_WritePin(Trolley_IN4_GPIO_Port, Trolley_IN4_Pin, GPIO_PIN_RESET);
            break;
    }
}

// ==== STEPPER MOTOR IMPLEMENTATION ====

void SlewMotor_Init(void)
{
    HAL_TIM_Base_Start_IT(&htim5);

    // Reset all coils
    HAL_GPIO_WritePin(Slew_IN1_GPIO_Port, Slew_IN1_Pin, GPIO_PIN_RESET);
    HAL_GPIO_WritePin(Slew_IN2_GPIO_Port, Slew_IN2_Pin, GPIO_PIN_RESET);
    HAL_GPIO_WritePin(Slew_IN3_GPIO_Port, Slew_IN3_Pin, GPIO_PIN_RESET);
    HAL_GPIO_WritePin(Slew_IN4_GPIO_Port, Slew_IN4_Pin, GPIO_PIN_RESET);

    SlewMotor_Coast();
}

static void Stepper_SetPins(int idx)
{
    HAL_GPIO_WritePin(Slew_IN1_GPIO_Port, Slew_IN1_Pin, step_seq[idx][0]);
    HAL_GPIO_WritePin(Slew_IN2_GPIO_Port, Slew_IN2_Pin, step_seq[idx][1]);
    HAL_GPIO_WritePin(Slew_IN3_GPIO_Port, Slew_IN3_Pin, step_seq[idx][2]);
    HAL_GPIO_WritePin(Slew_IN4_GPIO_Port, Slew_IN4_Pin, step_seq[idx][3]);
}

void SlewMotor_Set(float rpm, StepperMotorDirection dir)
{
    if (dir == HOLD || rpm <= 0.0f) {
        step_dir = 0;
    } else {
        step_dir = (dir == CLOCKWISE) ? 1 : -1;
    }

    if (rpm > 0.0f) {
        step_interval_ms = (uint32_t)(60000.0f / (rpm * steps_per_rev));
    }
}

void SlewMotor_Coast(void)
{
    coast_flag = 1;
}

void Stepper_Tick(void)
{
    if (step_dir == 0)
    {
        if (coast_flag) {
            HAL_GPIO_WritePin(Slew_IN1_GPIO_Port, Slew_IN1_Pin, GPIO_PIN_RESET);
            HAL_GPIO_WritePin(Slew_IN2_GPIO_Port, Slew_IN2_Pin, GPIO_PIN_RESET);
            HAL_GPIO_WritePin(Slew_IN3_GPIO_Port, Slew_IN3_Pin, GPIO_PIN_RESET);
            HAL_GPIO_WritePin(Slew_IN4_GPIO_Port, Slew_IN4_Pin, GPIO_PIN_RESET);
        } else {
            Stepper_SetPins(step_index);
        }
        return;
    }

    // Normal step sequence
    if (step_dir > 0)
        step_index = (step_index + 1) % 4;
    else
        step_index = (step_index + 3) % 4;

    Stepper_SetPins(step_index);
}

// ==== TIMER CALLBACK HOOK ====
void Stepper_Timer_Callback(void) {
    static uint32_t counter = 0;
    counter++;

    if (counter >= step_interval_ms)
    {
        Stepper_Tick();
        counter = 0;
    }
}

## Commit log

2025-12-17 first documentation, pcb files
    [STM32Nucleo_L476RG_Baseboard-B_Cu.gbr, STM32Nucleo_L476RG_Baseboard-B_Mask.gbr, STM32Nucleo_L476RG_Baseboard-B_Paste.gbr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]
2025-12-17 pcb images

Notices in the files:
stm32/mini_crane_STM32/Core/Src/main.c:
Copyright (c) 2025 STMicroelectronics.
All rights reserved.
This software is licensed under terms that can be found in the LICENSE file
